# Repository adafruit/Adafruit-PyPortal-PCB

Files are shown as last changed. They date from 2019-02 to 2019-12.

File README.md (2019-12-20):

## Adafruit PyPortal - CircuitPython Powered Internet Display PCB

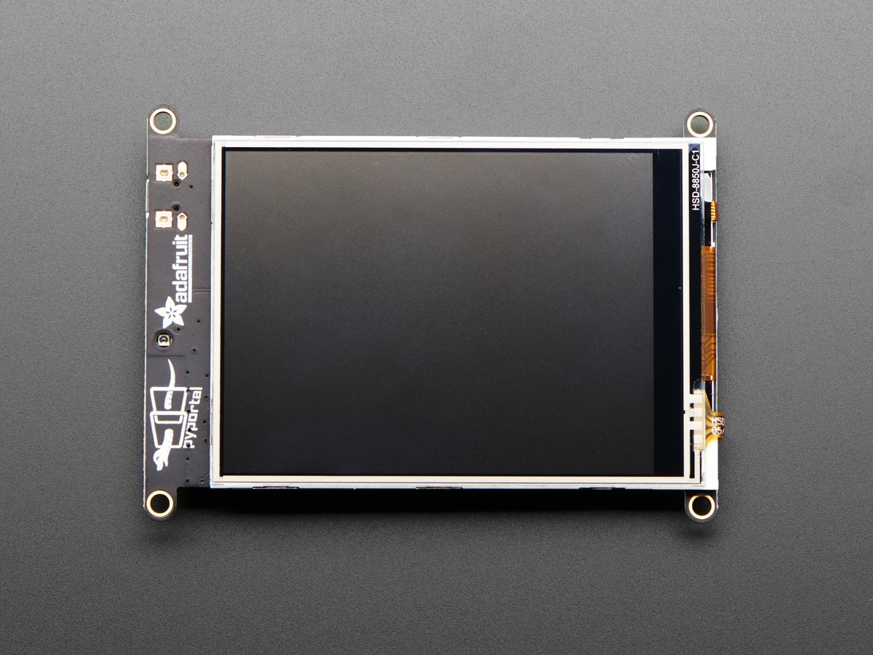
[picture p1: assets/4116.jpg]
<br/>
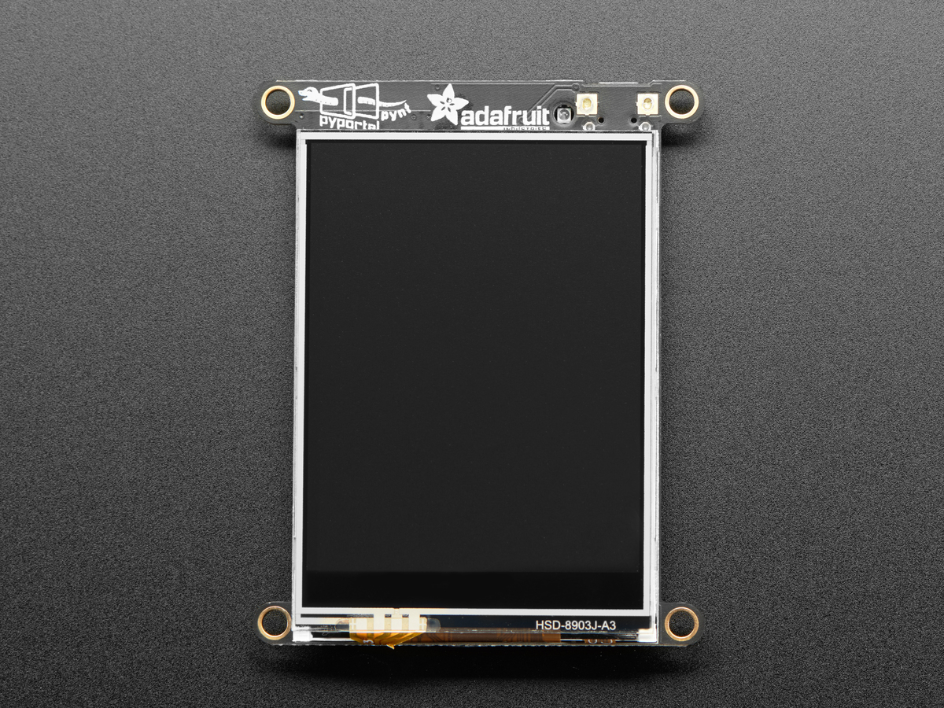
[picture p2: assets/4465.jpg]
<br/>
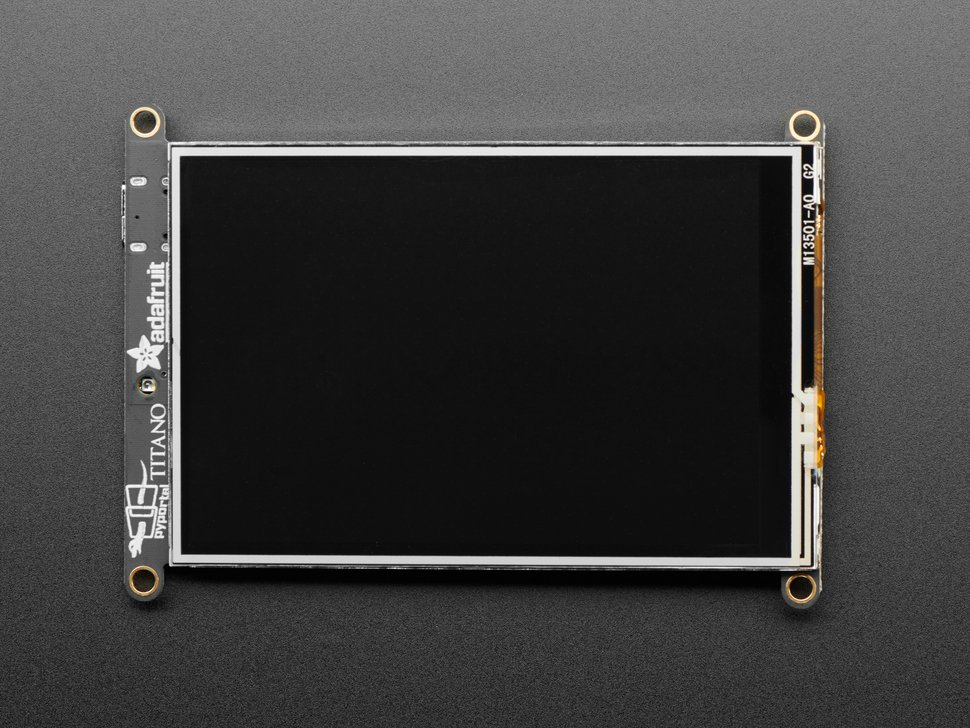
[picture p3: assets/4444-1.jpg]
<br/>

PCB files for the Adafruit PyPortal - CircuitPython Powered Internet Display and PyPortal Pynt. Format is EagleCAD schematic and board layout
* https://www.adafruit.com/product/4116
* https://www.adafruit.com/product/4465
* https://www.adafruit.com/product/4444

### Description

**PyPortal**, our easy-to-use IoT device that allows you to create all the things for the “Internet of Things” in minutes. Make custom touch screen interface GUIs, all open-source, and Python-powered using tinyJSON / APIs to get news, stock, weather, cat photos, and more – all over Wi-Fi with the latest technologies. Create little pocket universes of joy that connect to something good. Rotate it 90 degrees, it’s a web-connected conference badge #badgelife.

The PyPortal uses an ATMEL (Microchip) ATSAMD51J20, and an Espressif ESP32 Wi-Fi coprocessor with TLS/SSL support built-in. PyPortal has a **3.2″ 320 x 240 color TFT** with resistive touch screen. PyPortal includes: speaker, light sensor, temperature sensor, NeoPixel, microSD card slot, 8MB flash, plug-in ports for I2C and 2 analog/digital pins, 3D files for custom enclosures / lanyard fastening. Open-source hardware, and Open-Source software, CircuitPython and Arduino. The device shows up as a USB drive and the code (Python) can be edited in any IDE, text editor, etc.

The PyPortal Pynt is the little sister to our popular PyPortal - zapped with a shink ray to take the design from a 3.2" diagonal down to 2.4" diagonal screen - but otherwise the same! **Compared to the PyPortal, the Pynt does not include a ADT7410 temperature sensor. Other than the ADT7410, the Pynt's display, processor, STEMMA conectors and WiFi have the exact same wiring as the original 3.2" PyPortal so all Arduino/CircuitPython code will run exactly the same - just smaller!**

The M4 and ESP32 are a great couple - and each bring their own strengths to this board. The SAMD51 M4 has native USB so it can show up like a disk drive, act as a MIDI or HID keyboard/mouse, and of course bootload and debug over a serial port. It also has DACs, ADC, PWM, and tons of GPIO. Meanwhile, the ESP32 has secure WiFi capabilities, and plenty of Flash and RAM to buffer sockets. By letting the ESP32 focus on the complex TLS/SSL computation and socket buffering, it frees up the SAMD51 to act as the user interface. You get a great programming experience thanks to the native USB with files available for drag-n-drop, and you don't have to spend a ton of processor time and memory to do SSL encryption/decryption and certificate management. It's the best of both worlds!

**Please note:** You may get a version with DigiKey + Analog Devices branding or in plain style. The hardware is identical.

### License

Adafruit invests time and resources providing this open source design, please support Adafruit and open-source hardware by purchasing products from [Adafruit](https://www.adafruit.com)!

Designed by Limor Fried/Ladyada for Adafruit Industries.

Creative Commons Attribution/Share-Alike, all text above must be included in any redistribution. See license.txt for additional details.

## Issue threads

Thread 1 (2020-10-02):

Please make a PyPortal with more GPIO pins

zouden, 2020-10-02:
The PyPortal is a really useful board for making user interfaces. But it lacks enough GPIO pins to drive external hardware. The D3/D4 pins are limited in that only one of them can do PWM and both have series resistors.

A row of GPIO pins or pads on the side of the board would go a long way!

ladyada, 2020-10-02:
ok

Closed 2020-10-02.

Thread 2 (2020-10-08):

Error in silkscreen on Pyportal Pynt

zouden, 2020-10-08:
STEMMA connectors D3 and D4 are labelled incorrectly (swapped).

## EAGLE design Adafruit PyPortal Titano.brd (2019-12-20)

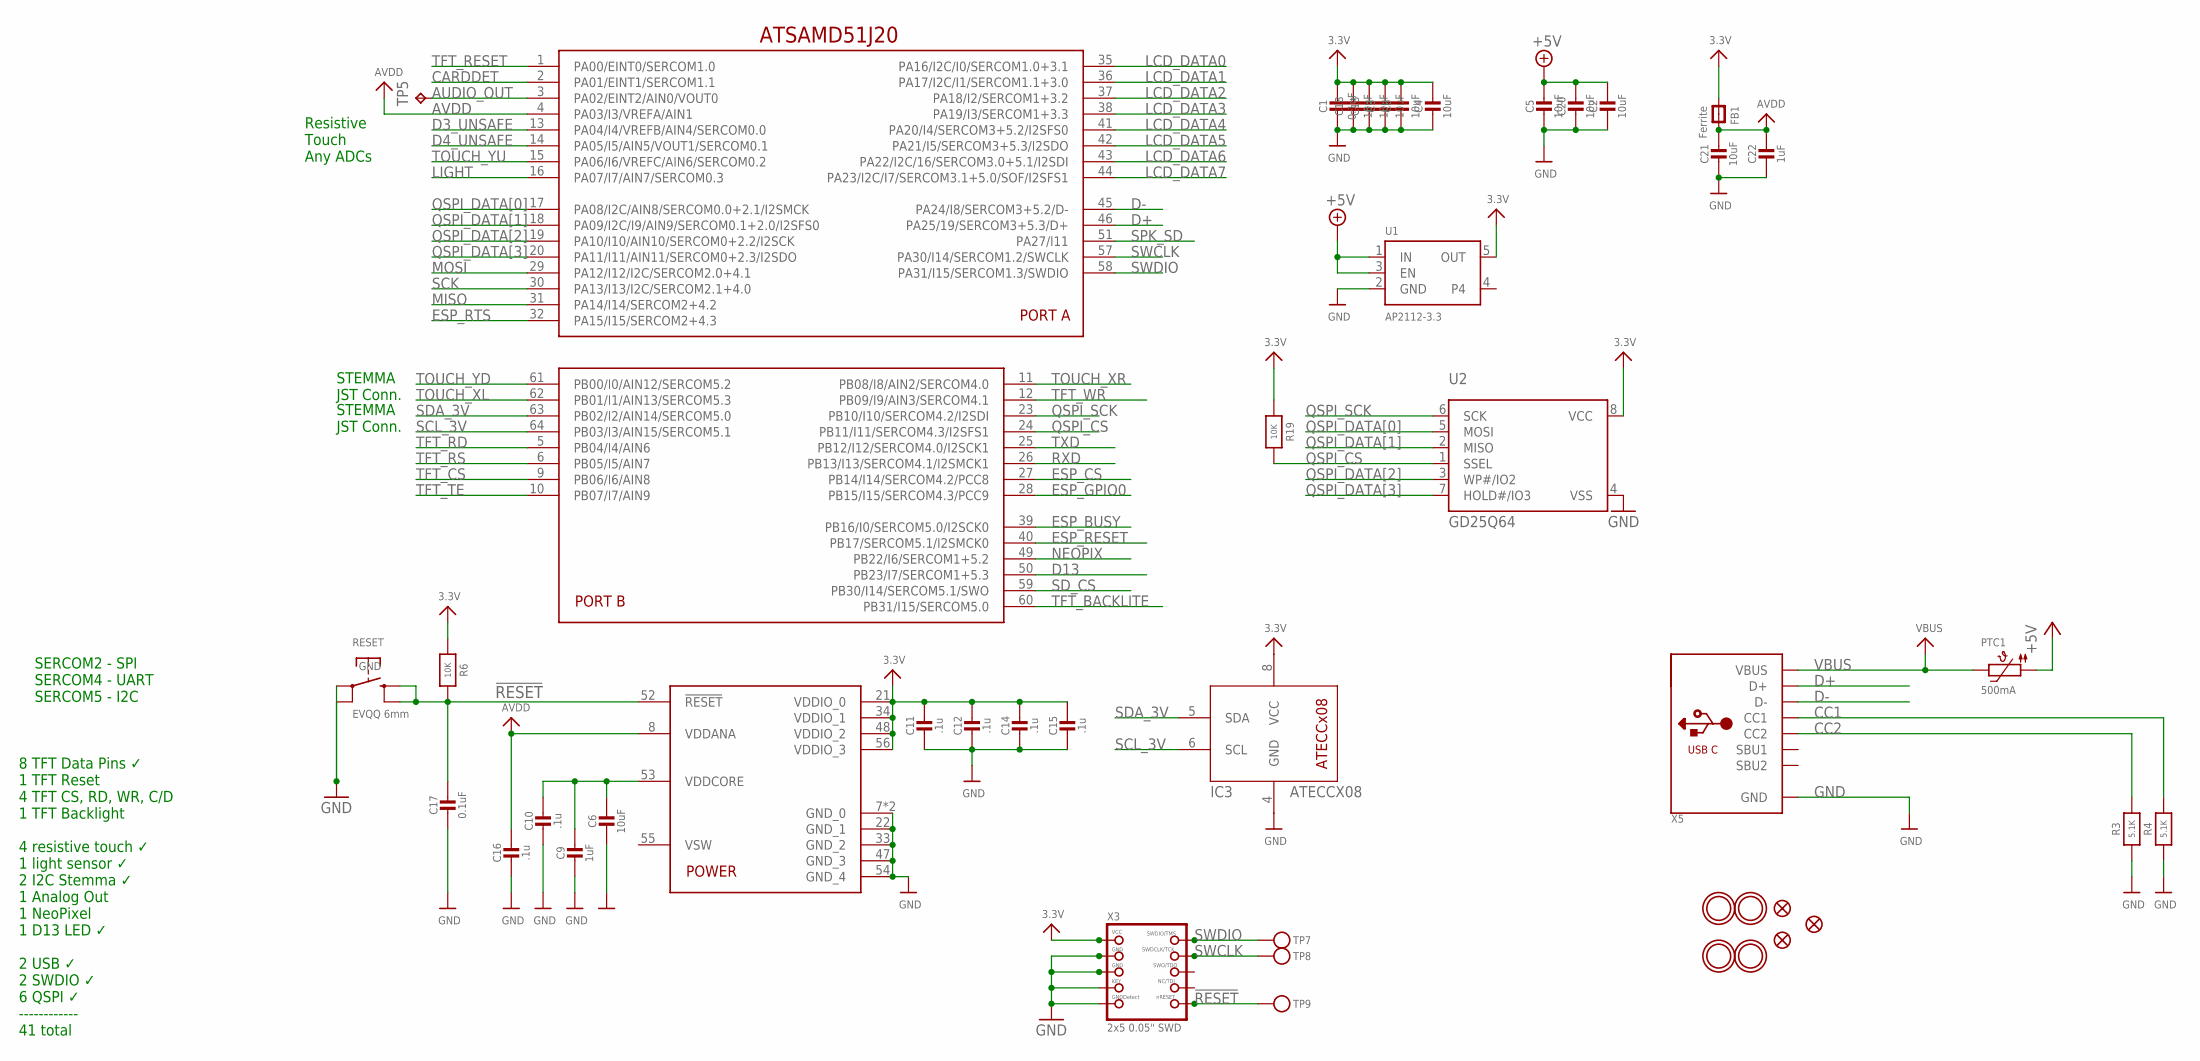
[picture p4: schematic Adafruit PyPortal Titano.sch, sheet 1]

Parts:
C1, C17: 0.1uF; 0603-NO
C2, C3, C4, C5, C6, C8, C13, C18, C20, C21: 10uF; 0805-NO
C9, C22: 1uF; 0603-NO
C10, C11, C12, C14, C15, C16: .1u; 0603-NO
FB1: Ferrite; 0805-NO
IC3: ATECCX08; SOIC8_150MIL
PTC1: 500mA; 1206
R3, R4: 5.1K; 0603-NO
R6, R19: 10K; 0603-NO
RESET: EVQQ 6mm; EVQ-Q2_SMALLER
TP5: TPTP15R; TP15R
TP7, TP8, TP9: TESTPOINTROUND1.5MM; TESTPOINT_ROUND_1.5MM
U1: AP2112-3.3; SOT23-5
U2: GD25Q64; SOIC8_208MIL
U$2: ATSAMD51J20; PQFN64-1
U$7, U$15, U$16, U$17: MOUNTINGHOLE3.0THIN; MOUNTINGHOLE_3.0_PLATEDTHIN
U$9, U$11, U$23: FIDUCIAL_1MM
X3: 2x5 0.05" SWD; 2X05_1.27MM_BOX_POSTS
X5: USB_C; USB_C_CUSB31-CFM2AX-01-X

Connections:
3.3V: C1.1, C3.1, C4.1, C8.1, C11.2, C12.2, C13.1, C14.2, C15.2, C18.1, FB1.1, IC3.8 (VCC), R6.1, R19.1, U1.5 (OUT), U2.8 (VCC), U$2.21 (VDDIO_0), U$2.34 (VDDIO_1), U$2.48 (VDDIO_2), U$2.56 (VDDIO_3), X3.1 (VCC); also elsewhere on the board
!RESET: C17.2, R6.2, RESET.B (S), RESET.B' (S1), TP9.P$1, U$2.52 (!RESET), X3.10 (NRESET)
+5V: C2.1, C5.1, C20.1, PTC1.1, U1.1 (IN), U1.3 (EN); also elsewhere on the board
AUDIO_OUT: TP5.TP, U$2.3 (PA02/EINT2/AIN0/VOUT0); also elsewhere on the board
AVDD: C16.2, C21.1, C22.1, FB1.2, U$2.4 (PA03/I3/VREFA/AIN1), U$2.8 (VDDANA)
CARDDET: U$2.2 (PA01/EINT1/SERCOM1.1); also elsewhere on the board
CC1: R4.2, X5.A5 (CC1)
CC2: R3.2, X5.B5 (CC2)
D3_UNSAFE: U$2.13 (PA04/I4/VREFB/AIN4/SERCOM0.0); also elsewhere on the board
D4_UNSAFE: U$2.14 (PA05/I5/AIN5/VOUT1/SERCOM0.1); also elsewhere on the board
D13: U$2.50 (PB23/I7/SERCOM1+5.3); also elsewhere on the board
D+: U$2.46 (PA25/19/SERCOM3+5.3/D+), X5.A6 (D+), X5.B6 (D+)
D-: U$2.45 (PA24/I8/SERCOM3+5.2/D-), X5.A7 (D-), X5.B7 (D-)
ESP_BUSY: U$2.39 (PB16/I0/SERCOM5.0/I2SCK0); also elsewhere on the board
ESP_CS: U$2.27 (PB14/I14/SERCOM4.2/PCC8); also elsewhere on the board
ESP_GPIO0: U$2.28 (PB15/I15/SERCOM4.3/PCC9); also elsewhere on the board
ESP_RESET: U$2.40 (PB17/SERCOM5.1/I2SMCK0); also elsewhere on the board
ESP_RTS: U$2.32 (PA15/I15/SERCOM2+4.3); also elsewhere on the board
GND: C1.2, C2.2, C3.2, C4.2, C5.2, C6.2, C8.2, C9.2, C10.1, C11.1, C12.1, C13.2, C14.1, C15.1, C16.1, C17.1, C18.2, C20.2, C21.2, C22.2, IC3.4 (GND), R3.1, R4.1, RESET.A, RESET.A' (P1), U1.2 (GND), U2.4 (VSS), U$2.7 (GND_0), U$2.22 (GND_1), U$2.33 (GND_2), U$2.47 (GND_3), U$2.54 (GND_4), U$2.EXP (GND_0), X3.3 (GND), X3.5 (GND), X3.7 (KEY), X3.9 (GNDDETECT), X5.A1B12 (GND), X5.B1A12 (GND); also elsewhere on the board
LCD_DATA0: U$2.35 (PA16/I2C/I0/SERCOM1.0+3.1); also elsewhere on the board
LCD_DATA1: U$2.36 (PA17/I2C/I1/SERCOM1.1+3.0); also elsewhere on the board
LCD_DATA2: U$2.37 (PA18/I2/SERCOM1+3.2); also elsewhere on the board
LCD_DATA3: U$2.38 (PA19/I3/SERCOM1+3.3); also elsewhere on the board
LCD_DATA4: U$2.41 (PA20/I4/SERCOM3+5.2/I2SFS0); also elsewhere on the board
LCD_DATA5: U$2.42 (PA21/I5/SERCOM3+5.3/I2SDO); also elsewhere on the board
LCD_DATA6: U$2.43 (PA22/I2C/16/SERCOM3.0+5.1/I2SDI); also elsewhere on the board
LCD_DATA7: U$2.44 (PA23/I2C/I7/SERCOM3.1+5.0/SOF/I2SFS1); also elsewhere on the board
LIGHT: U$2.16 (PA07/I7/AIN7/SERCOM0.3); also elsewhere on the board
MISO: U$2.31 (PA14/I14/SERCOM2+4.2); also elsewhere on the board
MOSI: U$2.29 (PA12/I12/I2C/SERCOM2.0+4.1); also elsewhere on the board
NEOPIX: U$2.49 (PB22/I6/SERCOM1+5.2); also elsewhere on the board
QSPI_CS: R19.2, U2.1 (SSEL), U$2.24 (PB11/I11/SERCOM4.3/I2SFS1)
QSPI_DATA[0]: U2.5 (MOSI), U$2.17 (PA08/I2C/AIN8/SERCOM0.0+2.1/I2SMCK)
QSPI_DATA[1]: U2.2 (MISO), U$2.18 (PA09/I2C/I9/AIN9/SERCOM0.1+2.0/I2SFS0)
QSPI_DATA[2]: U2.3 (WP#/IO2), U$2.19 (PA10/I10/AIN10/SERCOM0+2.2/I2SCK)
QSPI_DATA[3]: U2.7 (HOLD#/IO3), U$2.20 (PA11/I11/AIN11/SERCOM0+2.3/I2SDO)
QSPI_SCK: U2.6 (SCK), U$2.23 (PB10/I10/SERCOM4.2/I2SDI)
RXD: U$2.26 (PB13/I13/SERCOM4.1/I2SMCK1); also elsewhere on the board
SCK: U$2.30 (PA13/I13/I2C/SERCOM2.1+4.0); also elsewhere on the board
SCL_3V: IC3.6 (SCL), U$2.64 (PB03/I3/AIN15/SERCOM5.1); also elsewhere on the board
SDA_3V: IC3.5 (SDA), U$2.63 (PB02/I2/AIN14/SERCOM5.0); also elsewhere on the board
SD_CS: U$2.59 (PB30/I14/SERCOM5.1/SWO); also elsewhere on the board
SPK_SD: U$2.51 (PA27/I11); also elsewhere on the board
SWCLK: TP8.P$1, U$2.57 (PA30/I14/SERCOM1.2/SWCLK), X3.4 (SWDCLK)
SWDIO: TP7.P$1, U$2.58 (PA31/I15/SERCOM1.3/SWDIO), X3.2 (SWDIO)
TFT_BACKLITE: U$2.60 (PB31/I15/SERCOM5.0); also elsewhere on the board
TFT_CS: U$2.9 (PB06/I6/AIN8); also elsewhere on the board
TFT_RD: U$2.5 (PB04/I4/AIN6); also elsewhere on the board
TFT_RESET: U$2.1 (PA00/EINT0/SERCOM1.0); also elsewhere on the board
TFT_RS: U$2.6 (PB05/I5/AIN7); also elsewhere on the board
TFT_TE: U$2.10 (PB07/I7/AIN9); also elsewhere on the board
TFT_WR: U$2.12 (PB09/I9/AIN3/SERCOM4.1); also elsewhere on the board
TOUCH_XL: U$2.62 (PB01/I1/AIN13/SERCOM5.3); also elsewhere on the board
TOUCH_XR: U$2.11 (PB08/I8/AIN2/SERCOM4.0); also elsewhere on the board
TOUCH_YD: U$2.61 (PB00/I0/AIN12/SERCOM5.2); also elsewhere on the board
TOUCH_YU: U$2.15 (PA06/I6/VREFC/AIN6/SERCOM0.2); also elsewhere on the board
TXD: U$2.25 (PB12/I12/SERCOM4.0/I2SCK1); also elsewhere on the board
VBUS: PTC1.2, X5.A4B9 (VBUS), X5.B4A9 (VBUS)
VDDCORE: C6.1, C9.1, C10.2, U$2.53 (VDDCORE)

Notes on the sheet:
ATSAMD51J20
8 TFT Data Pins ✓ 1 TFT Reset 4 TFT CS, RD, WR, C/D 1 TFT Backlight 4 resistive touch ✓ 1 light sensor ✓ 2 I2C Stemma ✓ 1 Analog Out 1 NeoPixel 1 D13 LED ✓ 2 USB ✓ 2 SWDIO ✓ 6 QSPI ✓ ------------ 41 total
STEMMA JST Conn.
Resistive Touch Any ADCs
SERCOM2 - SPI SERCOM4 - UART SERCOM5 - I2C

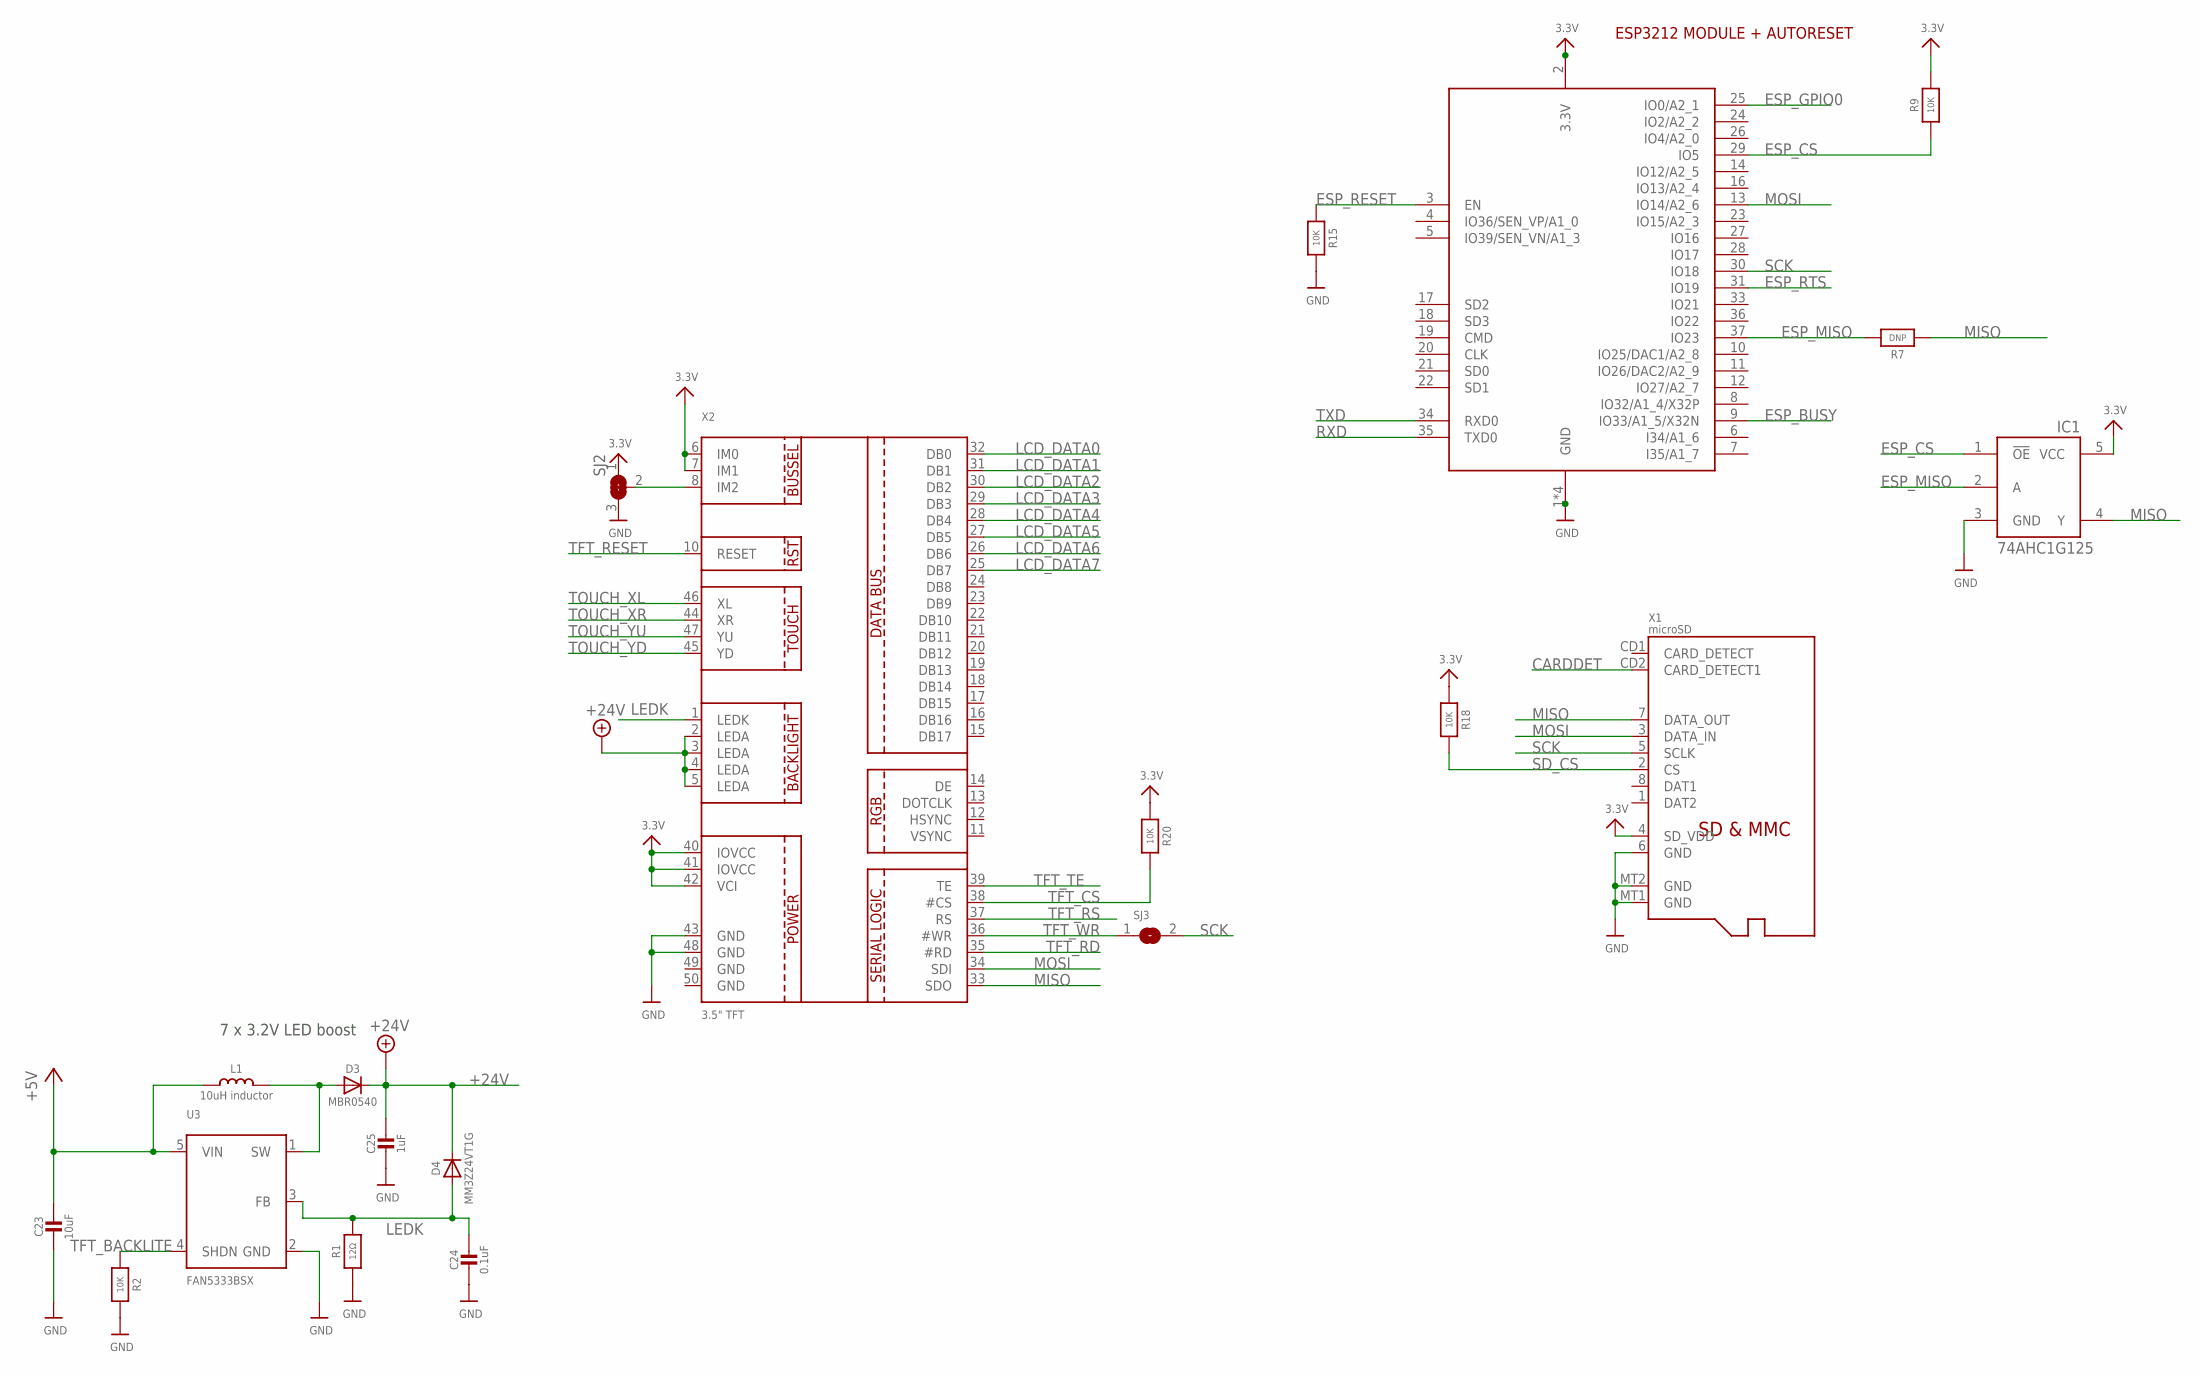
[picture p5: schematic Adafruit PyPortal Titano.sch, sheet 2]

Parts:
C23: 10uF; 0805-NO
C24: 0.1uF; 0805-NO
C25: 1uF; 0805-NO
D3: MBR0540; SOD-123
D4: MM3Z24VT1G; SMADIODE
IC1: 74AHC1G125; SOT23-5L
L1: 10uH inductor; INDUCTOR_5X5MM_NR5040_NOTHERMALS
R1: 12Ω; 0805-NO
R2, R9, R15, R18, R20: 10K; 0603-NO
R7: DNP; 0603-NO
SJ2: SOLDERJUMPER_2WAY; SOLDERJUMPER_2WAY_OPEN_NOPASTE
SJ3: SOLDERJUMPER; SOLDERJUMPER_ARROW_NOPASTE
U3: FAN5333BSX; SOT23-5
X1: microSD; MICROSD
X2: 3.5" TFT; TFT_3.5IN_320X480_50PIN
X6: ESP32_WROOM32; WROOM32

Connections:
3.3V: IC1.5 (VCC), R9.2, R18.1, R20.1, SJ2.1, X1.4 (SD_VDD), X2.6 (IM0), X2.7 (IM1), X2.40 (IOVCC), X2.41 (IOVCC), X2.42 (VCI), X6.2 (3.3V); also elsewhere on the board
+5V: C23.1, L1.P$1 (1), U3.5 (VIN); also elsewhere on the board
+24V: C25.1, D3.C, D4.C, X2.2 (LEDA), X2.3 (LEDA), X2.4 (LEDA), X2.5 (LEDA)
CARDDET: X1.CD2 (CARD_DETECT1); also elsewhere on the board
ESP_BUSY: X6.9 (IO33/A1_5/X32N); also elsewhere on the board
ESP_CS: IC1.1 (!OE), R9.1, X6.29 (IO5); also elsewhere on the board
ESP_GPIO0: X6.25 (IO0/A2_1); also elsewhere on the board
ESP_MISO: IC1.2 (A), R7.2, X6.37 (IO23)
ESP_RESET: R15.1, X6.3 (EN); also elsewhere on the board
ESP_RTS: X6.31 (IO19); also elsewhere on the board
GND: C23.2, C24.2, C25.2, IC1.3 (GND), R1.1, R2.2, R15.2, SJ2.3, U3.2 (GND), X1.6 (GND), X1.MT1 (GND), X1.MT2 (GND), X2.43 (GND), X2.48 (GND), X6.1 (GND), X6.15 (GND), X6.38 (GND), X6.P$1 (GND); also elsewhere on the board
LCD_DATA0: X2.32 (DB0); also elsewhere on the board
LCD_DATA1: X2.31 (DB1); also elsewhere on the board
LCD_DATA2: X2.30 (DB2); also elsewhere on the board
LCD_DATA3: X2.29 (DB3); also elsewhere on the board
LCD_DATA4: X2.28 (DB4); also elsewhere on the board
LCD_DATA5: X2.27 (DB5); also elsewhere on the board
LCD_DATA6: X2.26 (DB6); also elsewhere on the board
LCD_DATA7: X2.25 (DB7); also elsewhere on the board
LEDK: C24.1, D4.A, R1.2, U3.3 (FB), X2.1 (LEDK)
MISO: IC1.4 (Y), R7.1, X1.7 (DATA_OUT), X2.33 (SDO); also elsewhere on the board
MOSI: X1.3 (DATA_IN), X2.34 (SDI), X6.13 (IO14/A2_6); also elsewhere on the board
unnamed: SJ2.2, X2.8 (IM2)
unnamed: D3.A, L1.P$2 (2), U3.1 (SW)
RXD: X6.35 (TXD0); also elsewhere on the board
SCK: SJ3.2, X1.5 (SCLK), X6.30 (IO18); also elsewhere on the board
SD_CS: R18.2, X1.2 (CS); also elsewhere on the board
TFT_BACKLITE: R2.1, U3.4 (SHDN); also elsewhere on the board
TFT_CS: R20.2, X2.38 (#CS); also elsewhere on the board
TFT_RD: X2.35 (#RD); also elsewhere on the board
TFT_RESET: X2.10 (RESET); also elsewhere on the board
TFT_RS: X2.37 (RS); also elsewhere on the board
TFT_TE: X2.39 (TE); also elsewhere on the board
TFT_WR: SJ3.1, X2.36 (#WR); also elsewhere on the board
TOUCH_XL: X2.46 (XL); also elsewhere on the board
TOUCH_XR: X2.44 (XR); also elsewhere on the board
TOUCH_YD: X2.45 (YD); also elsewhere on the board
TOUCH_YU: X2.47 (YU); also elsewhere on the board
TXD: X6.34 (RXD0); also elsewhere on the board

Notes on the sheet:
ESP3212 MODULE + AUTORESET
7 x 3.2V LED boost

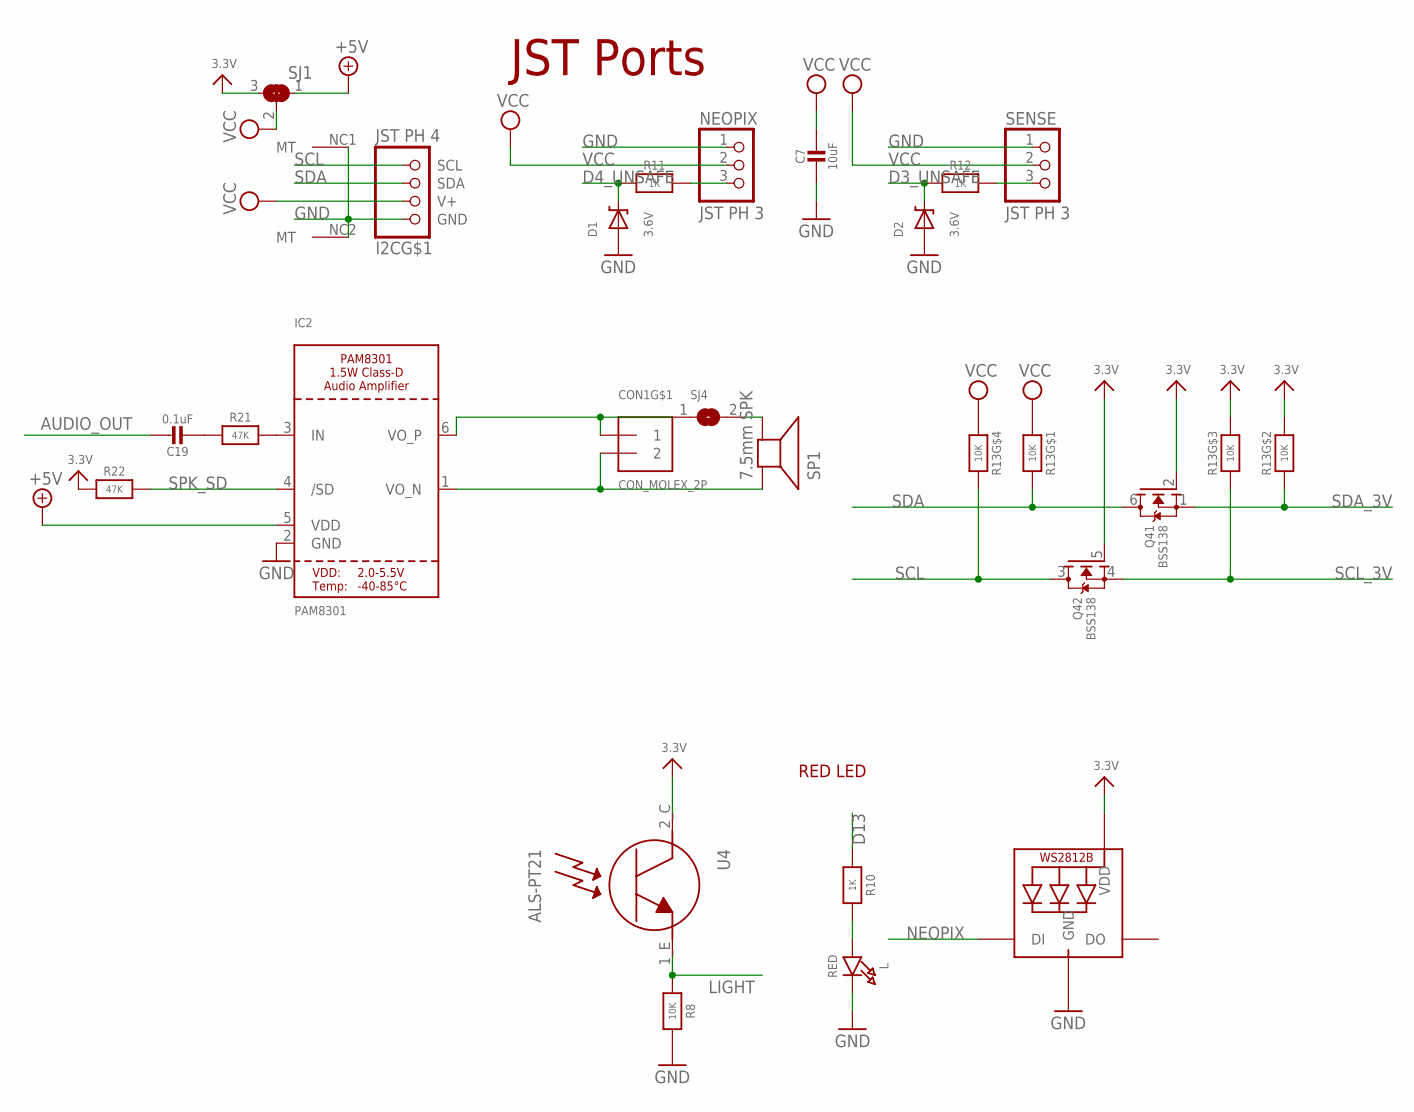
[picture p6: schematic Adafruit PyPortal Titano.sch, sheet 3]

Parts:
C7: 10uF; 0805-NO
C19: 0.1uF; 0603-NO
CON1: CON_MOLEX_2P; 53398-0271
D1, D2: 3.6V; SOD-323
I2C: JST PH 4; JSTPH4
IC2: PAM8301; SOT23-6
L: RED; CHIPLED_0805_NOOUTLINE
LED1: WS2812B3535; LED3535
NEOPIX: JST PH 3; JSTPH3
Q4: BSS138; SOT363
R8: 10K; 0603-NO
R10, R11, R12: 1K; 0603-NO
R13: 10K; RESPACK_4X0603
R21, R22: 47K; 0603-NO
SENSE: JST PH 3; JSTPH3
SJ1: SOLDERJUMPER_2WAY; SOLDERJUMPER_2WAY_OPEN_NOPASTE
SJ4: SOLDERJUMPERCLOSED; SOLDERJUMPER_CLOSEDWIRE
SP1: 7.5mm SPK; BUZZER_SMT_7.5MM
U4: ALS-PT21; ALS-PT26-21C

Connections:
3.3V: LED1.2 (VDD), Q4.2 (G), Q4.5 (G), R13.2 (1), R13.3 (1), R22.1, SJ1.3, U4.2_C (C); also elsewhere on the board
+5V: IC2.5 (VDD), SJ1.1; also elsewhere on the board
AUDIO_OUT: C19.1; also elsewhere on the board
D3: R12.1, SENSE.3
D3_UNSAFE: D2.C, R12.2; also elsewhere on the board
D4: NEOPIX.3, R11.1
D4_UNSAFE: D1.C, R11.2; also elsewhere on the board
D13: R10.1; also elsewhere on the board
GND: C7.2, D1.A, D2.A, I2C.1 (GND), I2C.NC1 (MT), I2C.NC2 (MT), IC2.2 (GND), L.C, LED1.4 (GND), NEOPIX.1, R8.1, SENSE.1; also elsewhere on the board
LIGHT: R8.2, U4.1_E (E); also elsewhere on the board
unnamed: L.A, R10.2
unnamed: C19.2, R21.1
unnamed: IC2.3 (IN), R21.2
unnamed: SJ4.2, SP1.-
NEOPIX: LED1.1 (DI); also elsewhere on the board
SCL: I2C.4 (SCL), Q4.3 (D), R13.5 (2)
SCL_3V: Q4.4 (S), R13.6 (2); also elsewhere on the board
SDA: I2C.3 (SDA), Q4.6 (D), R13.8 (2)
SDA_3V: Q4.1 (S), R13.7 (2); also elsewhere on the board
SPKR+: CON1.2, IC2.1 (VO_N), SP1.+
SPK_SD: IC2.4 (/SD), R22.2; also elsewhere on the board
SPRK-: CON1.1, IC2.6 (VO_P), SJ4.1
VCC: C7.1, I2C.2 (V+), NEOPIX.2, R13.1, R13.4 (1), SENSE.2, SJ1.2

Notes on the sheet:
RED LED
JST Ports

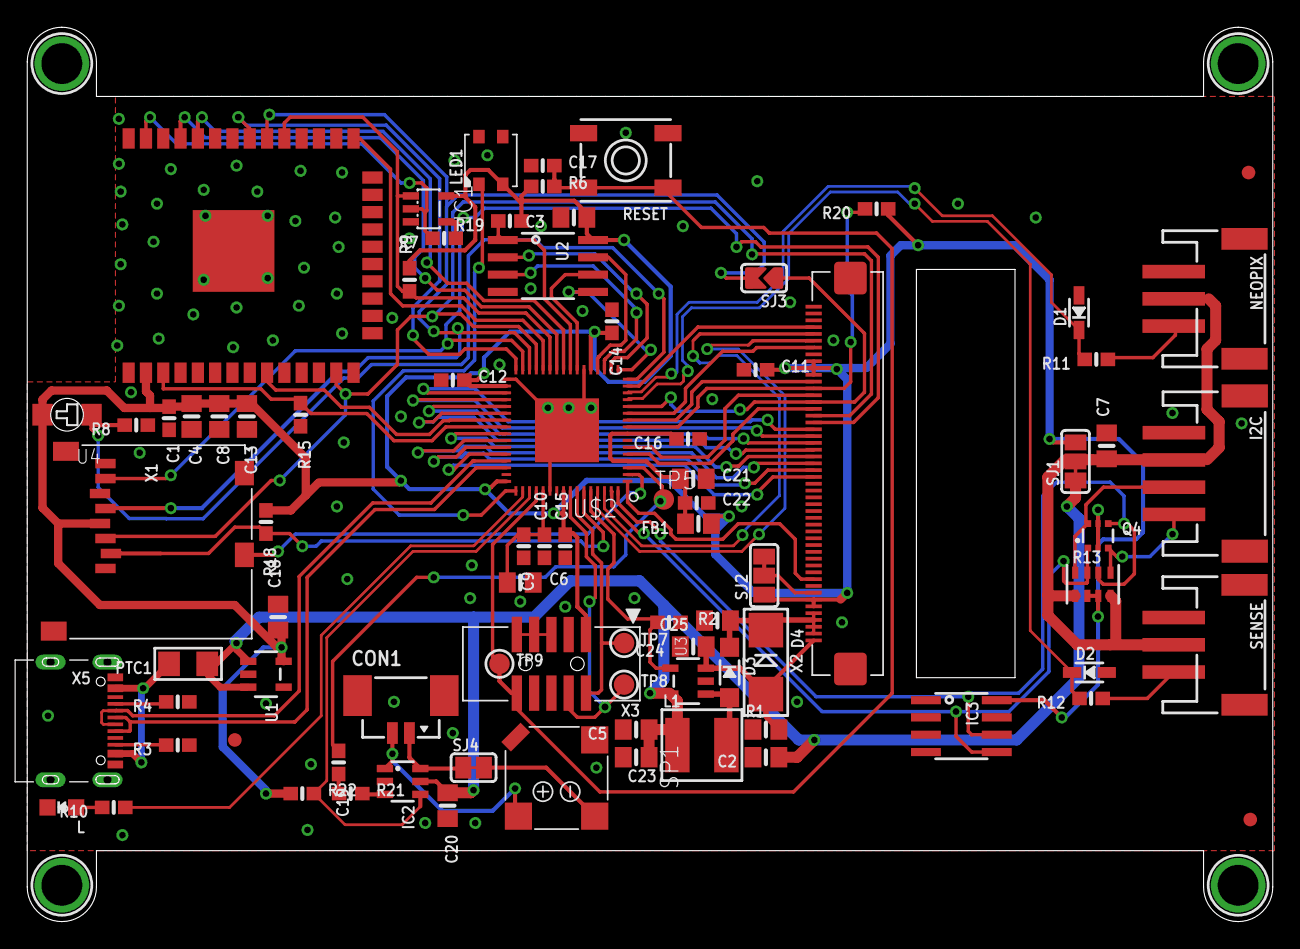
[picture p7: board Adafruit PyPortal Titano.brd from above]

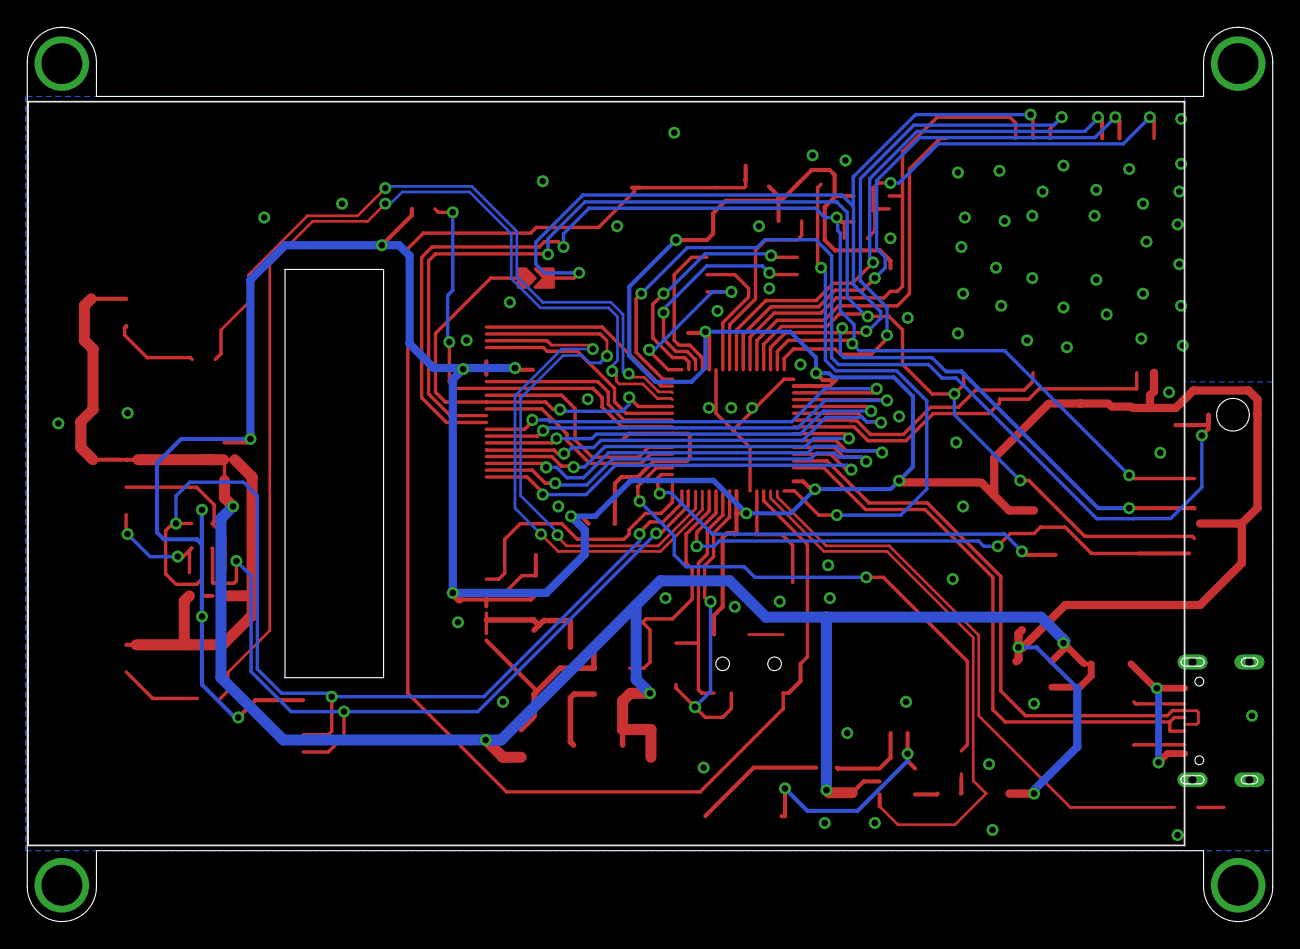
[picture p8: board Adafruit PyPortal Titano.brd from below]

Board: 2 copper layers, 91.4 x 65.7 mm, 89 parts (2 on the bottom side), 75 nets.

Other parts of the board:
U$19: PYPORTALTITANO_BOT
U$54: PYPORTALTITANO_TOP

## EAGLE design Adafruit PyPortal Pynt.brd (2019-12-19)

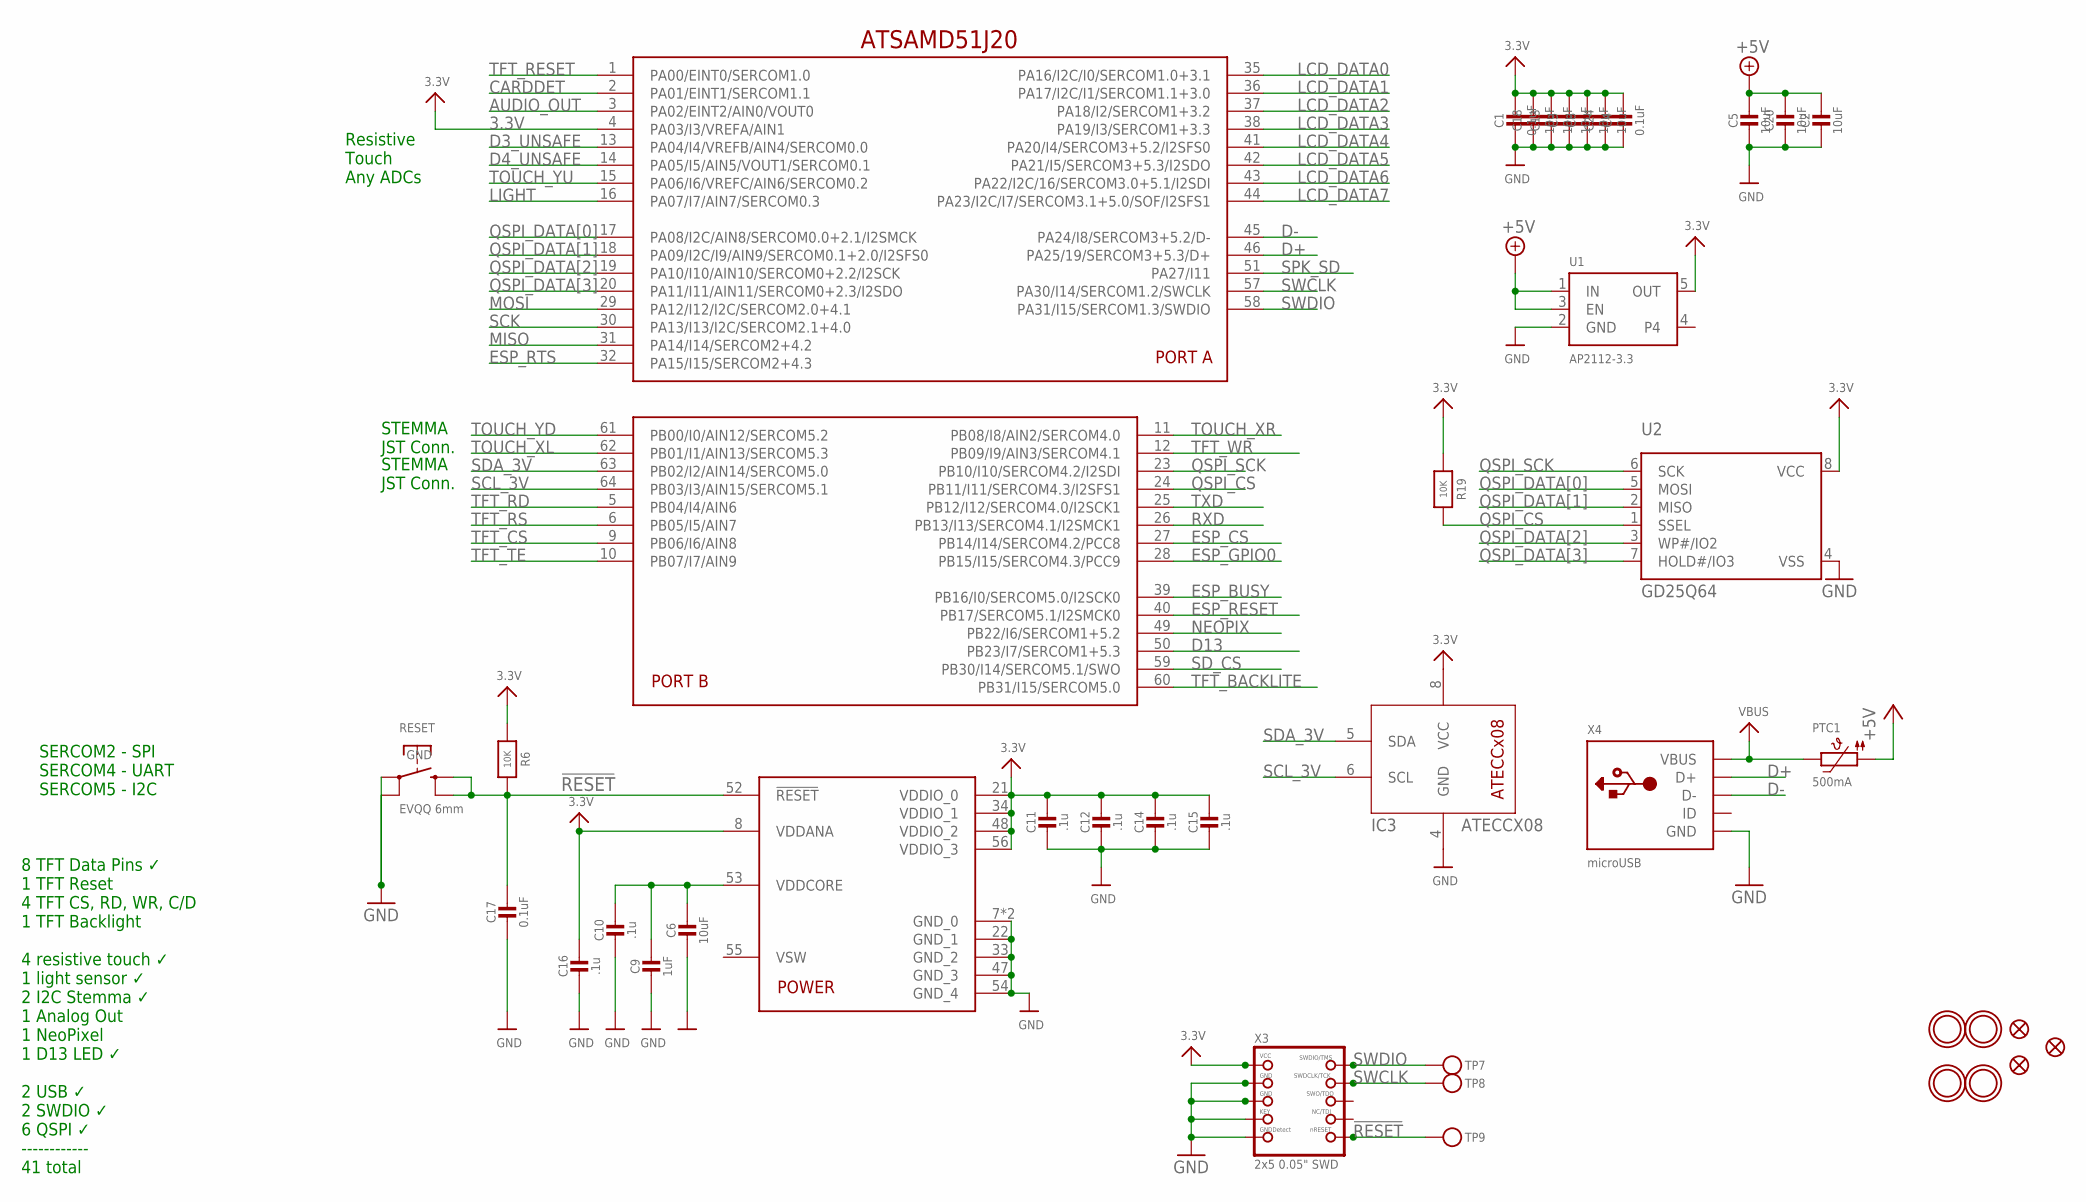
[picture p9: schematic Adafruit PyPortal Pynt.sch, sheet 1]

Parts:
C1, C17: 0.1uF; 0603-NO
C2, C3, C5, C6, C8, C13, C18, C20, C24: 10uF; 0805-NO
C4: 0.1uF; 0805-NO
C9: 1uF; 0603-NO
C10, C11, C12, C14, C15, C16: .1u; 0603-NO
IC3: ATECCX08; SOIC8_150MIL
PTC1: 500mA; 1206
R6, R19: 10K; 0603-NO
RESET: EVQQ 6mm; EVQ-Q2_SMALLER
TP7, TP8, TP9: TESTPOINTROUND1.5MM; TESTPOINT_ROUND_1.5MM
U1: AP2112-3.3; SOT23-5
U2: GD25Q64; SOIC8_208MIL
U$2: ATSAMD51J20; PQFN64-1
U$7, U$15, U$16, U$17: MOUNTINGHOLE3.0THIN; MOUNTINGHOLE_3.0_PLATEDTHIN
U$9, U$11, U$23: FIDUCIAL_1MM
X3: 2x5 0.05" SWD; 2X05_1.27MM_SMT
X4: microUSB; 4UCONN_20329_NARROW

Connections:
3.3V: C1.1, C3.1, C4.1, C8.1, C11.2, C12.2, C13.1, C14.2, C15.2, C16.2, C18.1, C24.1, IC3.8 (VCC), R6.1, R19.1, U1.5 (OUT), U2.8 (VCC), U$2.4 (PA03/I3/VREFA/AIN1), U$2.8 (VDDANA), U$2.21 (VDDIO_0), U$2.34 (VDDIO_1), U$2.48 (VDDIO_2), U$2.56 (VDDIO_3), X3.1 (VCC); also elsewhere on the board
!RESET: C17.2, R6.2, RESET.B (S), RESET.B' (S1), TP9.P$1, U$2.52 (!RESET), X3.10 (NRESET)
+5V: C2.1, C5.1, C20.1, PTC1.1, U1.1 (IN), U1.3 (EN); also elsewhere on the board
AUDIO_OUT: U$2.3 (PA02/EINT2/AIN0/VOUT0); also elsewhere on the board
CARDDET: U$2.2 (PA01/EINT1/SERCOM1.1); also elsewhere on the board
D3_UNSAFE: U$2.13 (PA04/I4/VREFB/AIN4/SERCOM0.0); also elsewhere on the board
D4_UNSAFE: U$2.14 (PA05/I5/AIN5/VOUT1/SERCOM0.1); also elsewhere on the board
D13: U$2.50 (PB23/I7/SERCOM1+5.3); also elsewhere on the board
D+: U$2.46 (PA25/19/SERCOM3+5.3/D+), X4.D+
D-: U$2.45 (PA24/I8/SERCOM3+5.2/D-), X4.D-
ESP_BUSY: U$2.39 (PB16/I0/SERCOM5.0/I2SCK0); also elsewhere on the board
ESP_CS: U$2.27 (PB14/I14/SERCOM4.2/PCC8); also elsewhere on the board
ESP_GPIO0: U$2.28 (PB15/I15/SERCOM4.3/PCC9); also elsewhere on the board
ESP_RESET: U$2.40 (PB17/SERCOM5.1/I2SMCK0); also elsewhere on the board
ESP_RTS: U$2.32 (PA15/I15/SERCOM2+4.3); also elsewhere on the board
GND: C1.2, C2.2, C3.2, C4.2, C5.2, C6.2, C8.2, C9.2, C10.1, C11.1, C12.1, C13.2, C14.1, C15.1, C16.1, C17.1, C18.2, C20.2, C24.2, IC3.4 (GND), RESET.A, RESET.A' (P1), U1.2 (GND), U2.4 (VSS), U$2.7 (GND_0), U$2.22 (GND_1), U$2.33 (GND_2), U$2.47 (GND_3), U$2.54 (GND_4), U$2.EXP (GND_0), X3.3 (GND), X3.5 (GND), X3.7 (KEY), X3.9 (GNDDETECT), X4.BASE@1 (GND), X4.BASE@2 (GND), X4.GND, X4.SPRT@1 (GND), X4.SPRT@2 (GND), X4.SPRT@3 (GND), X4.SPRT@4 (GND); also elsewhere on the board
LCD_DATA0: U$2.35 (PA16/I2C/I0/SERCOM1.0+3.1); also elsewhere on the board
LCD_DATA1: U$2.36 (PA17/I2C/I1/SERCOM1.1+3.0); also elsewhere on the board
LCD_DATA2: U$2.37 (PA18/I2/SERCOM1+3.2); also elsewhere on the board
LCD_DATA3: U$2.38 (PA19/I3/SERCOM1+3.3); also elsewhere on the board
LCD_DATA4: U$2.41 (PA20/I4/SERCOM3+5.2/I2SFS0); also elsewhere on the board
LCD_DATA5: U$2.42 (PA21/I5/SERCOM3+5.3/I2SDO); also elsewhere on the board
LCD_DATA6: U$2.43 (PA22/I2C/16/SERCOM3.0+5.1/I2SDI); also elsewhere on the board
LCD_DATA7: U$2.44 (PA23/I2C/I7/SERCOM3.1+5.0/SOF/I2SFS1); also elsewhere on the board
LIGHT: U$2.16 (PA07/I7/AIN7/SERCOM0.3); also elsewhere on the board
MISO: U$2.31 (PA14/I14/SERCOM2+4.2); also elsewhere on the board
MOSI: U$2.29 (PA12/I12/I2C/SERCOM2.0+4.1); also elsewhere on the board
NEOPIX: U$2.49 (PB22/I6/SERCOM1+5.2); also elsewhere on the board
QSPI_CS: R19.2, U2.1 (SSEL), U$2.24 (PB11/I11/SERCOM4.3/I2SFS1)
QSPI_DATA[0]: U2.5 (MOSI), U$2.17 (PA08/I2C/AIN8/SERCOM0.0+2.1/I2SMCK)
QSPI_DATA[1]: U2.2 (MISO), U$2.18 (PA09/I2C/I9/AIN9/SERCOM0.1+2.0/I2SFS0)
QSPI_DATA[2]: U2.3 (WP#/IO2), U$2.19 (PA10/I10/AIN10/SERCOM0+2.2/I2SCK)
QSPI_DATA[3]: U2.7 (HOLD#/IO3), U$2.20 (PA11/I11/AIN11/SERCOM0+2.3/I2SDO)
QSPI_SCK: U2.6 (SCK), U$2.23 (PB10/I10/SERCOM4.2/I2SDI)
RXD: U$2.26 (PB13/I13/SERCOM4.1/I2SMCK1); also elsewhere on the board
SCK: U$2.30 (PA13/I13/I2C/SERCOM2.1+4.0); also elsewhere on the board
SCL_3V: IC3.6 (SCL), U$2.64 (PB03/I3/AIN15/SERCOM5.1); also elsewhere on the board
SDA_3V: IC3.5 (SDA), U$2.63 (PB02/I2/AIN14/SERCOM5.0); also elsewhere on the board
SD_CS: U$2.59 (PB30/I14/SERCOM5.1/SWO); also elsewhere on the board
SPK_SD: U$2.51 (PA27/I11); also elsewhere on the board
SWCLK: TP8.P$1, U$2.57 (PA30/I14/SERCOM1.2/SWCLK), X3.4 (SWDCLK)
SWDIO: TP7.P$1, U$2.58 (PA31/I15/SERCOM1.3/SWDIO), X3.2 (SWDIO)
TFT_BACKLITE: U$2.60 (PB31/I15/SERCOM5.0); also elsewhere on the board
TFT_CS: U$2.9 (PB06/I6/AIN8); also elsewhere on the board
TFT_RD: U$2.5 (PB04/I4/AIN6); also elsewhere on the board
TFT_RESET: U$2.1 (PA00/EINT0/SERCOM1.0); also elsewhere on the board
TFT_RS: U$2.6 (PB05/I5/AIN7); also elsewhere on the board
TFT_TE: U$2.10 (PB07/I7/AIN9); also elsewhere on the board
TFT_WR: U$2.12 (PB09/I9/AIN3/SERCOM4.1); also elsewhere on the board
TOUCH_XL: U$2.62 (PB01/I1/AIN13/SERCOM5.3); also elsewhere on the board
TOUCH_XR: U$2.11 (PB08/I8/AIN2/SERCOM4.0); also elsewhere on the board
TOUCH_YD: U$2.61 (PB00/I0/AIN12/SERCOM5.2); also elsewhere on the board
TOUCH_YU: U$2.15 (PA06/I6/VREFC/AIN6/SERCOM0.2); also elsewhere on the board
TXD: U$2.25 (PB12/I12/SERCOM4.0/I2SCK1); also elsewhere on the board
VBUS: PTC1.2, X4.VBUS
VDDCORE: C6.1, C9.1, C10.2, U$2.53 (VDDCORE)

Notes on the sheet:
ATSAMD51J20
8 TFT Data Pins ✓ 1 TFT Reset 4 TFT CS, RD, WR, C/D 1 TFT Backlight 4 resistive touch ✓ 1 light sensor ✓ 2 I2C Stemma ✓ 1 Analog Out 1 NeoPixel 1 D13 LED ✓ 2 USB ✓ 2 SWDIO ✓ 6 QSPI ✓ ------------ 41 total
STEMMA JST Conn.
Resistive Touch Any ADCs
SERCOM2 - SPI SERCOM4 - UART SERCOM5 - I2C

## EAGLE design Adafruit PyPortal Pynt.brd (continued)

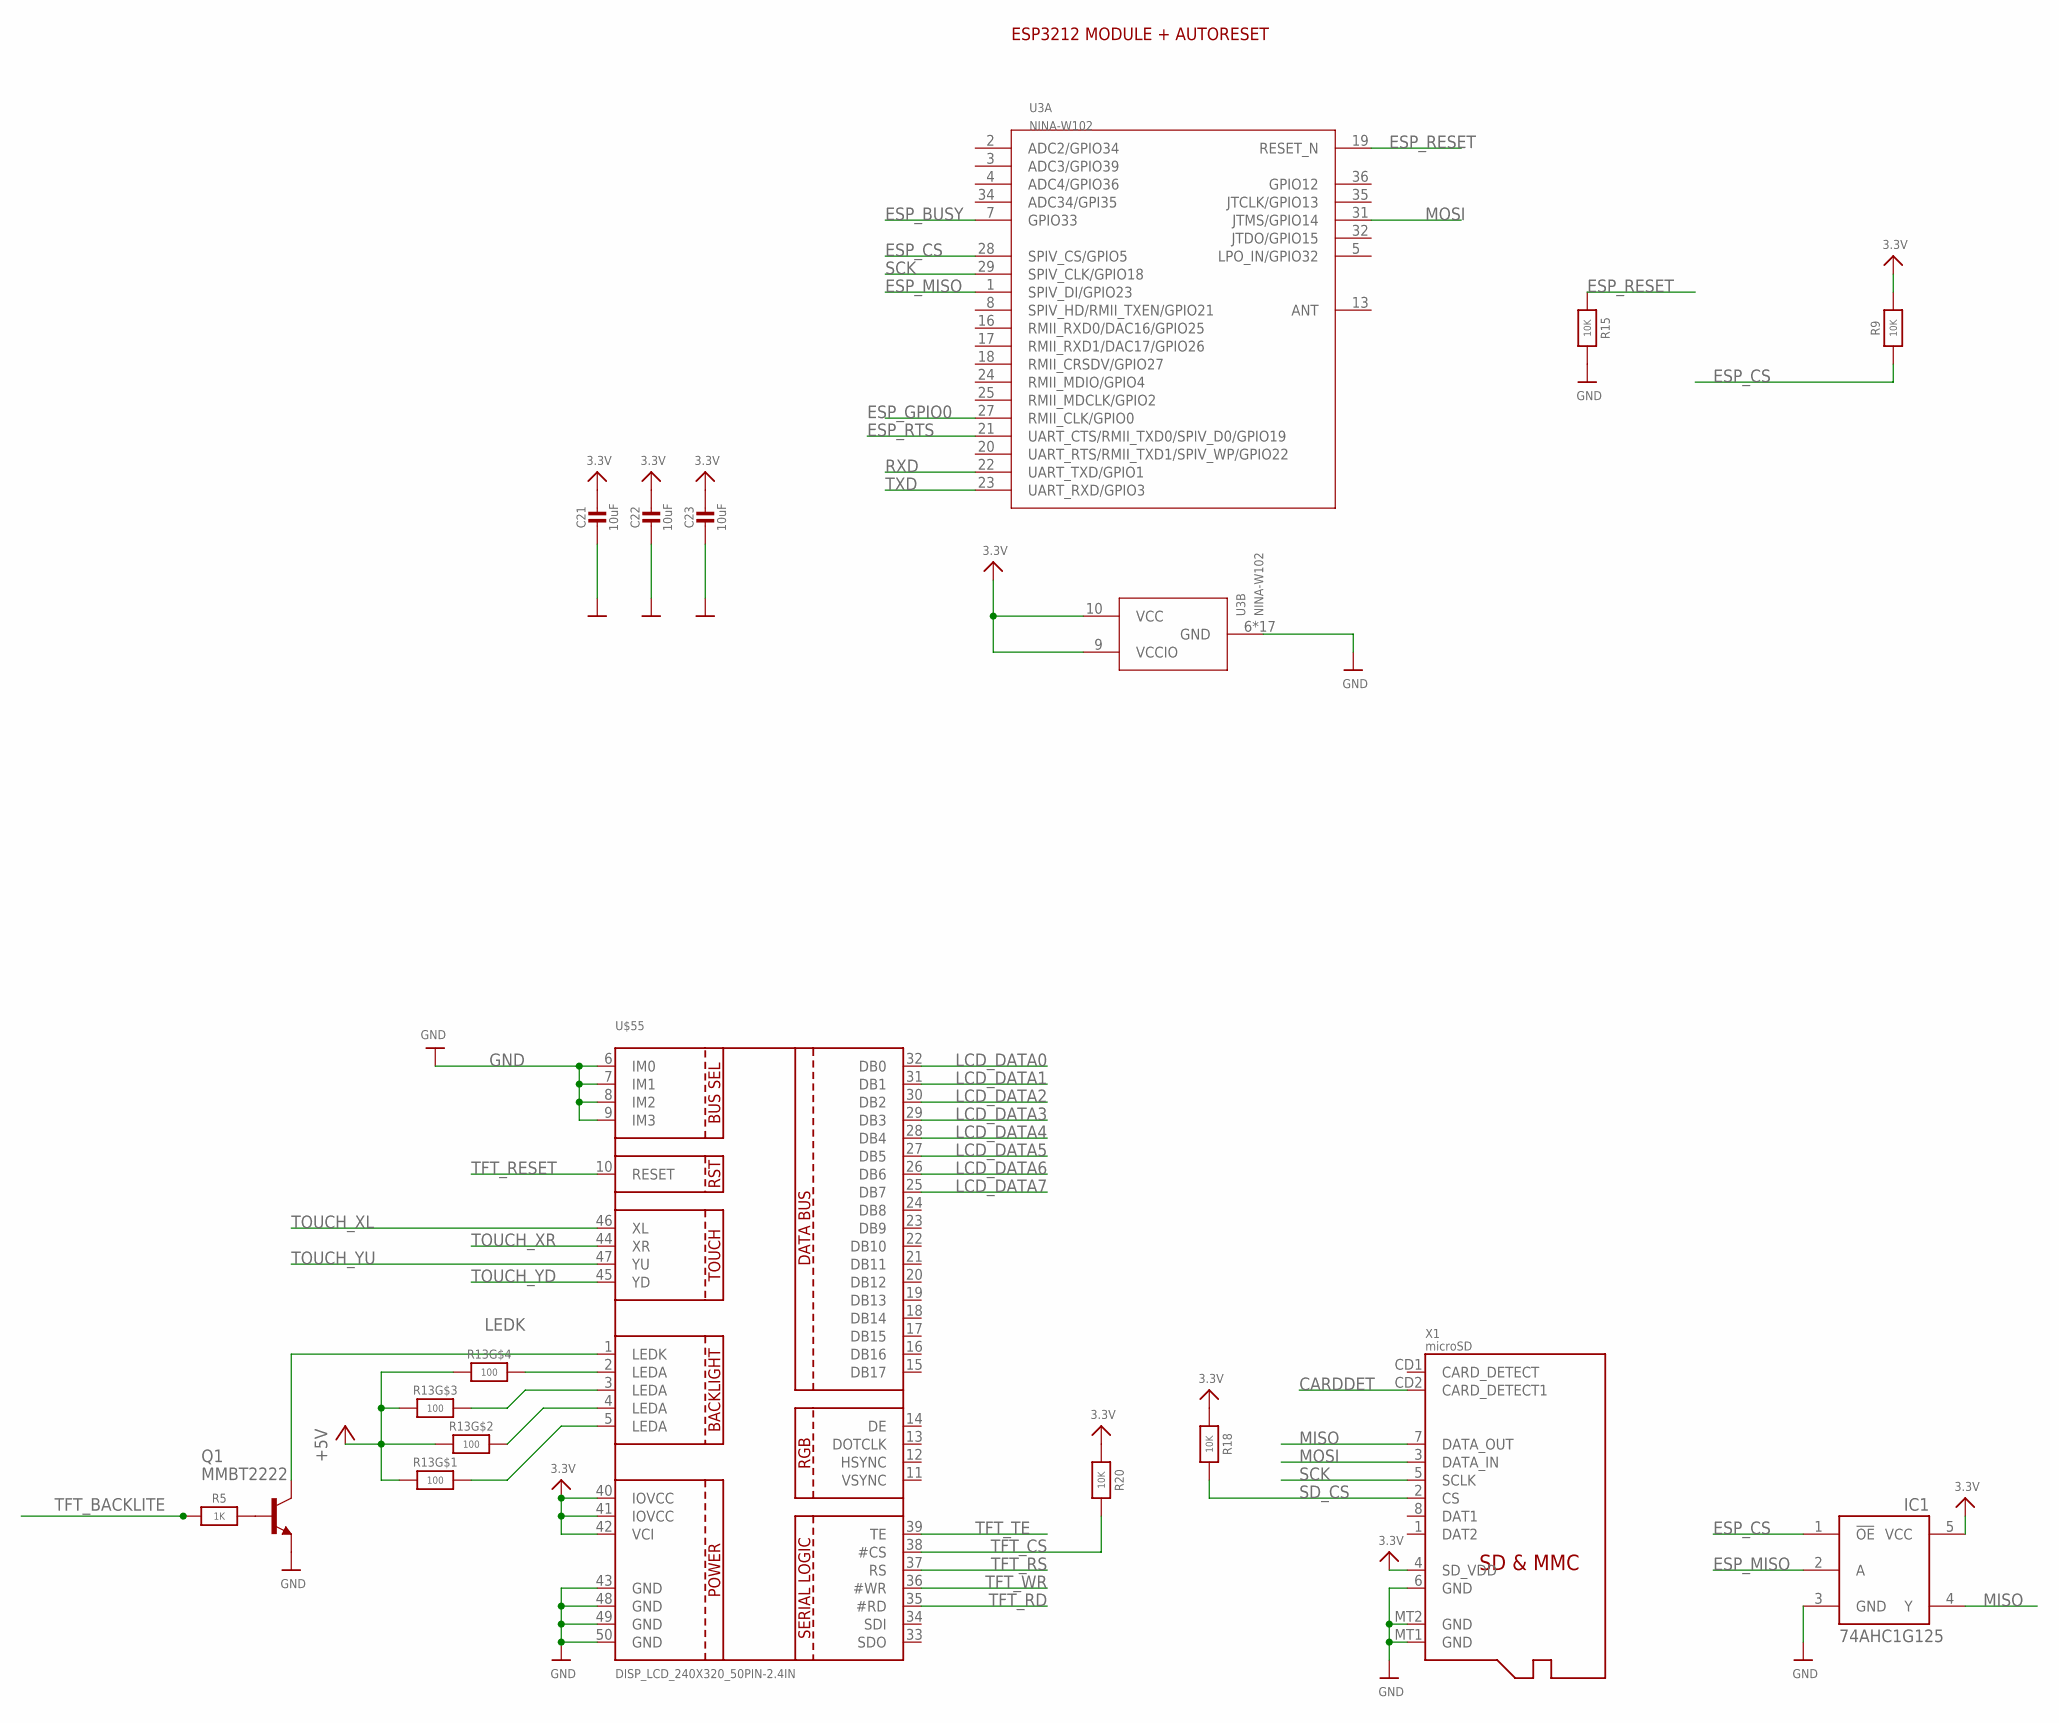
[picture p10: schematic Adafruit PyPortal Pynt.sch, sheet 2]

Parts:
C21, C22, C23: 10uF; 0805-NO
IC1: 74AHC1G125; SOT23-5L
Q1: MMBT2222; SOT23-BEC
R5: 1K; 0603-NO
R9, R15, R18, R20: 10K; 0603-NO
R13: 100; RESPACK_4X0603
U3: NINA-W102; ARDUINO-UCS&SOCS_NINA-W1X
U$55: DISP_LCD_240X320_50PIN-2.4IN; TFT_2.4IN_240X320_50PIN
X1: microSD; MICROSD

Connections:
3.3V: C21.1, C22.1, C23.1, IC1.5 (VCC), R9.2, R18.1, R20.1, U3.9 (VCCIO), U3.10 (VCC), U$55.40 (IOVCC), U$55.41 (IOVCC), U$55.42 (VCI), X1.4 (SD_VDD); also elsewhere on the board
+5V: R13.1, R13.2 (1), R13.3 (1), R13.4 (1); also elsewhere on the board
CARDDET: X1.CD2 (CARD_DETECT1); also elsewhere on the board
ESP_BUSY: U3.7 (GPIO33); also elsewhere on the board
ESP_CS: IC1.1 (!OE), R9.1, U3.28 (SPIV_CS/GPIO5); also elsewhere on the board
ESP_GPIO0: U3.27 (RMII_CLK/GPIO0); also elsewhere on the board
ESP_MISO: IC1.2 (A), U3.1 (SPIV_DI/GPIO23)
ESP_RESET: R15.1, U3.19 (RESET_N); also elsewhere on the board
ESP_RTS: U3.21 (UART_CTS/RMII_TXD0/SPIV_D0/GPIO19); also elsewhere on the board
GND: C21.2, C22.2, C23.2, IC1.3 (GND), Q1.E, R15.2, U3.6 (GND), U3.12 (GND), U3.14 (GND), U3.26 (GND), U3.30 (GND), U3.GND@1 (GND), U3.GND@2 (GND), U3.GND@3 (GND), U3.GND@4 (GND), U3.GND@5 (GND), U3.GND@6 (GND), U3.GND@7 (GND), U3.GND@8 (GND), U3.GND@9 (GND), U3.GND@10 (GND), U3.GND@11 (GND), U3.GND@12 (GND), U$55.6 (IM0), U$55.7 (IM1), U$55.8 (IM2), U$55.9 (IM3), U$55.43 (GND), U$55.48 (GND), U$55.49 (GND), U$55.50 (GND), X1.6 (GND), X1.MT1 (GND), X1.MT2 (GND); also elsewhere on the board
LCD_DATA0: U$55.32 (DB0); also elsewhere on the board
LCD_DATA1: U$55.31 (DB1); also elsewhere on the board
LCD_DATA2: U$55.30 (DB2); also elsewhere on the board
LCD_DATA3: U$55.29 (DB3); also elsewhere on the board
LCD_DATA4: U$55.28 (DB4); also elsewhere on the board
LCD_DATA5: U$55.27 (DB5); also elsewhere on the board
LCD_DATA6: U$55.26 (DB6); also elsewhere on the board
LCD_DATA7: U$55.25 (DB7); also elsewhere on the board
LEDK: Q1.C, U$55.1 (LEDK)
MISO: IC1.4 (Y), X1.7 (DATA_OUT); also elsewhere on the board
MOSI: U3.31 (JTMS/GPIO14), X1.3 (DATA_IN); also elsewhere on the board
unnamed: R13.8 (2), U$55.5 (LEDA)
unnamed: R13.5 (2), U$55.2 (LEDA)
unnamed: R13.6 (2), U$55.3 (LEDA)
unnamed: R13.7 (2), U$55.4 (LEDA)
unnamed: Q1.B, R5.2
RXD: U3.22 (UART_TXD/GPIO1); also elsewhere on the board
SCK: U3.29 (SPIV_CLK/GPIO18), X1.5 (SCLK); also elsewhere on the board
SD_CS: R18.2, X1.2 (CS); also elsewhere on the board
TFT_BACKLITE: R5.1; also elsewhere on the board
TFT_CS: R20.2, U$55.38 (#CS); also elsewhere on the board
TFT_RD: U$55.35 (#RD); also elsewhere on the board
TFT_RESET: U$55.10 (RESET); also elsewhere on the board
TFT_RS: U$55.37 (RS); also elsewhere on the board
TFT_TE: U$55.39 (TE); also elsewhere on the board
TFT_WR: U$55.36 (#WR); also elsewhere on the board
TOUCH_XL: U$55.46 (XL); also elsewhere on the board
TOUCH_XR: U$55.44 (XR); also elsewhere on the board
TOUCH_YD: U$55.45 (YD); also elsewhere on the board
TOUCH_YU: U$55.47 (YU); also elsewhere on the board
TXD: U3.23 (UART_RXD/GPIO3); also elsewhere on the board

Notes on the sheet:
ESP3212 MODULE + AUTORESET

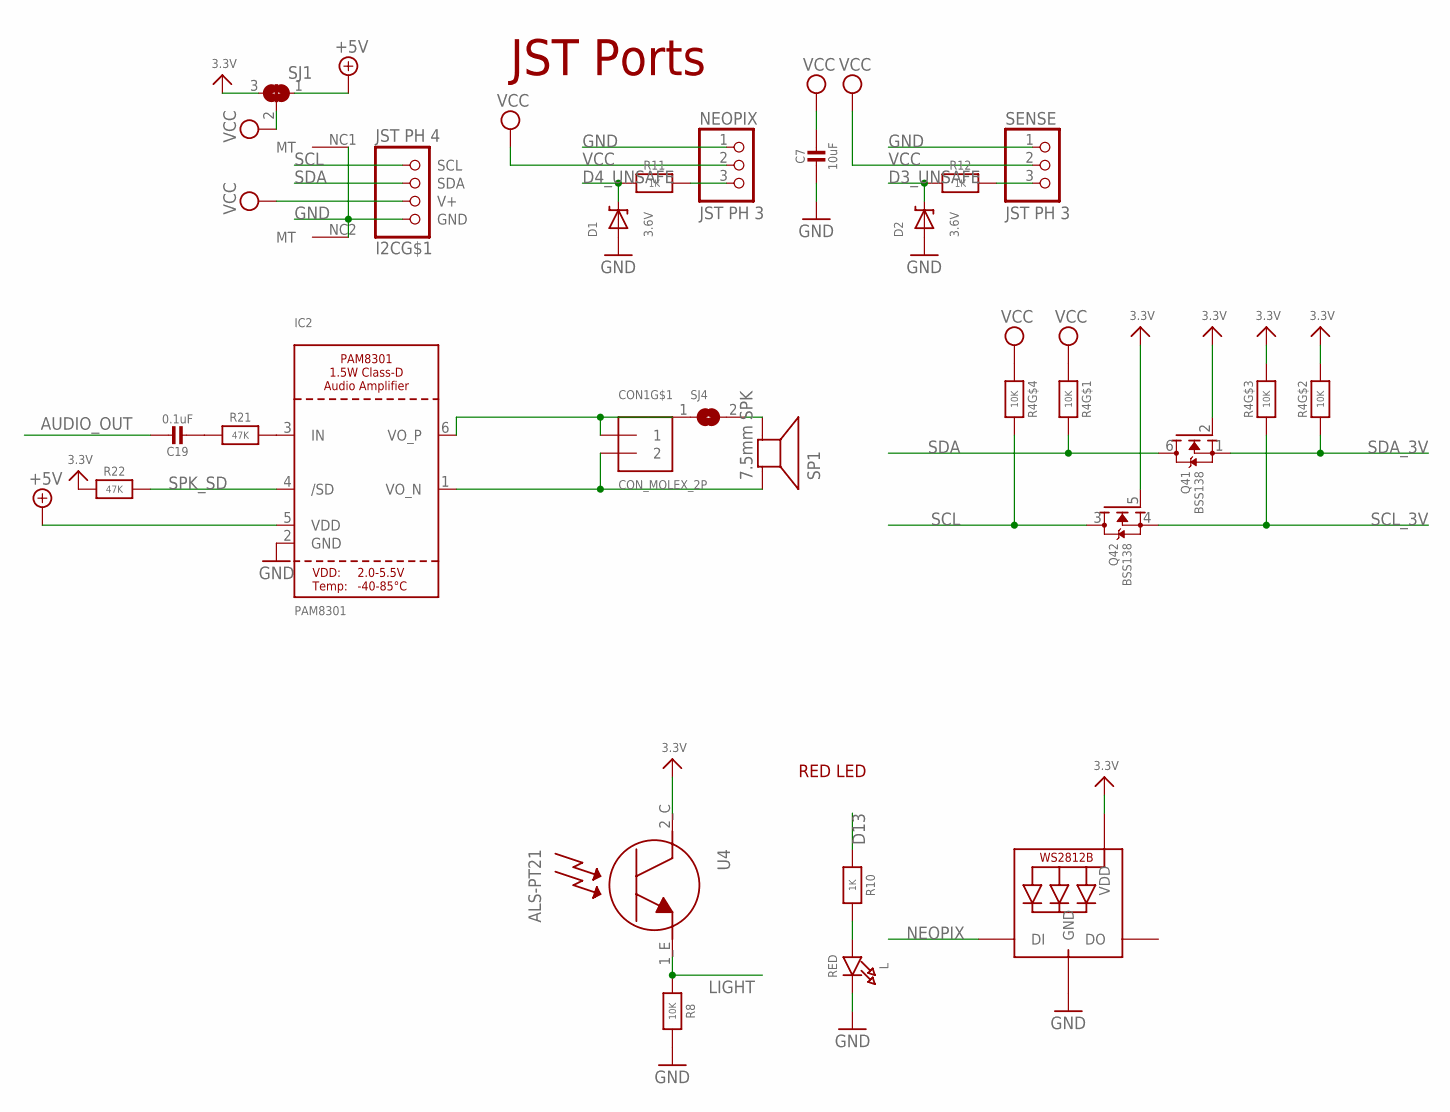
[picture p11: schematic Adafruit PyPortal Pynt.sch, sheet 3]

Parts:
C7: 10uF; 0805-NO
C19: 0.1uF; 0603-NO
CON1: CON_MOLEX_2P; 53398-0271
D1, D2: 3.6V; SOD-323
I2C: JST PH 4; JSTPH4
IC2: PAM8301; SOT23-6
L: RED; CHIPLED_0805_NOOUTLINE
LED1: WS2812B3535; LED3535
NEOPIX: JST PH 3; JSTPH3
Q4: BSS138; SOT363
R4: 10K; RESPACK_4X0603
R8: 10K; 0603-NO
R10, R11, R12: 1K; 0603-NO
R21, R22: 47K; 0603-NO
SENSE: JST PH 3; JSTPH3
SJ1: SOLDERJUMPER_2WAY; SOLDERJUMPER_2WAY_OPEN_NOPASTE
SJ4: SOLDERJUMPERCLOSED; SOLDERJUMPER_CLOSEDWIRE
SP1: 7.5mm SPK; BUZZER_SMT_7.5MM
U4: ALS-PT21; ALS-PT26-21C

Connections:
3.3V: LED1.2 (VDD), Q4.2 (G), Q4.5 (G), R4.2 (1), R4.3 (1), R22.1, SJ1.3, U4.2_C (C); also elsewhere on the board
+5V: IC2.5 (VDD), SJ1.1; also elsewhere on the board
AUDIO_OUT: C19.1; also elsewhere on the board
D3: R12.1, SENSE.3
D3_UNSAFE: D2.C, R12.2; also elsewhere on the board
D4: NEOPIX.3, R11.1
D4_UNSAFE: D1.C, R11.2; also elsewhere on the board
D13: R10.1; also elsewhere on the board
GND: C7.2, D1.A, D2.A, I2C.1 (GND), I2C.NC1 (MT), I2C.NC2 (MT), IC2.2 (GND), L.C, LED1.4 (GND), NEOPIX.1, R8.1, SENSE.1; also elsewhere on the board
LIGHT: R8.2, U4.1_E (E); also elsewhere on the board
unnamed: L.A, R10.2
unnamed: C19.2, R21.1
unnamed: IC2.3 (IN), R21.2
unnamed: SJ4.2, SP1.-
NEOPIX: LED1.1 (DI); also elsewhere on the board
SCL: I2C.4 (SCL), Q4.3 (D), R4.5 (2)
SCL_3V: Q4.4 (S), R4.6 (2); also elsewhere on the board
SDA: I2C.3 (SDA), Q4.6 (D), R4.8 (2)
SDA_3V: Q4.1 (S), R4.7 (2); also elsewhere on the board
SPKR+: CON1.2, IC2.1 (VO_N), SP1.+
SPK_SD: IC2.4 (/SD), R22.2; also elsewhere on the board
SPRK-: CON1.1, IC2.6 (VO_P), SJ4.1
VCC: C7.1, I2C.2 (V+), NEOPIX.2, R4.1, R4.4 (1), SENSE.2, SJ1.2

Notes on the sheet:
RED LED
JST Ports

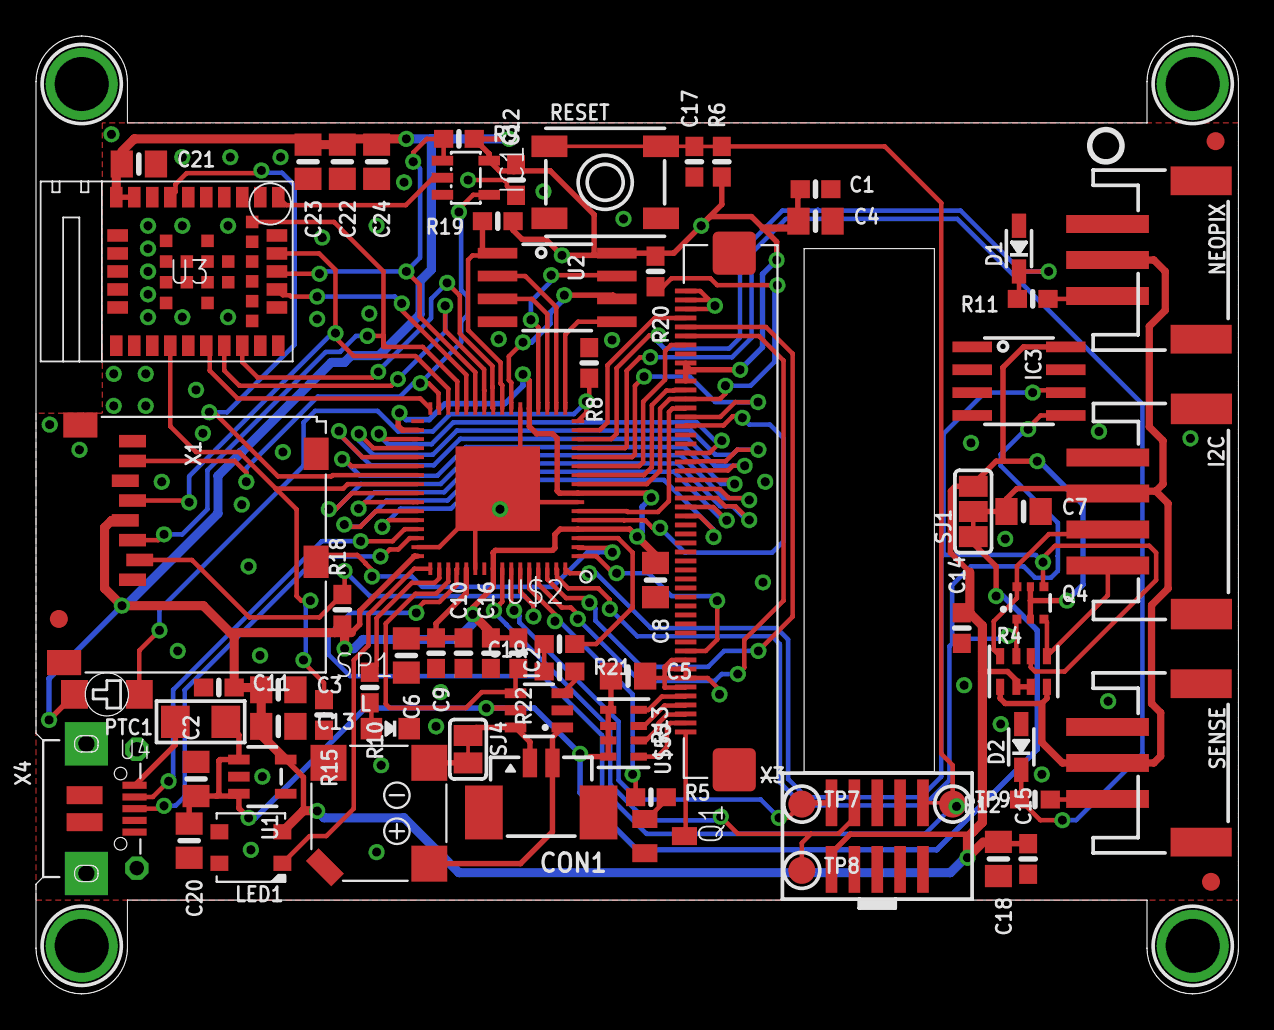
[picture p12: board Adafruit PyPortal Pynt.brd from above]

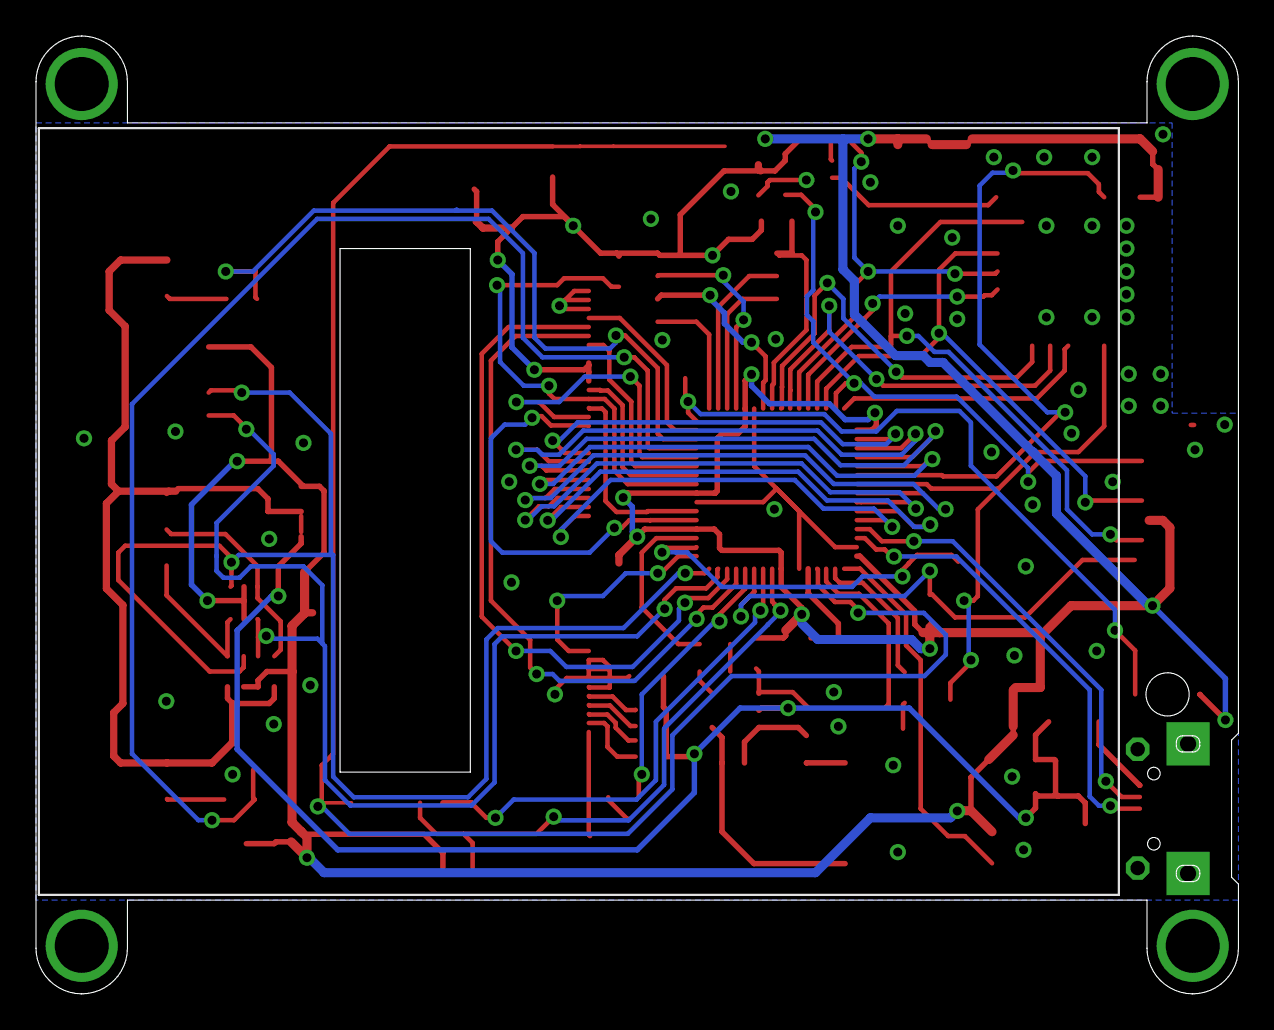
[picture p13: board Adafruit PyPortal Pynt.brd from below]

Board: 2 copper layers, 66.8 x 53.2 mm, 79 parts (2 on the bottom side), 74 nets.

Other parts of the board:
U$19: PYPORTALPYNT_TOP
U$54: PYPORTALPYNT_BOT
U$63: PCBFEAT-REV-040

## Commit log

2019-02-26 Add PCB files.
    [Adafruit PyPortal.brd, Adafruit PyPortal.sch]
2019-07-17 updated to use cookiecutter for pcb repos
2019-12-19 Adding Pynt PCB
    [Adafruit PyPortal Pynt.brd, Adafruit PyPortal Pynt.sch]
2019-12-20 Adding Titano board files.
    [Adafruit PyPortal Titano.brd, Adafruit PyPortal Titano.sch]
